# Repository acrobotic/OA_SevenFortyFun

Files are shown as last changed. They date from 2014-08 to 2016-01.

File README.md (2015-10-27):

## Ai\_Synth\_AVR

PCB design files (EAGLE) for a transistor-scale version of the μA741 Op-Amp
Integrated Circuit.

## Description

For more details, check out the product page at:

   * https://acrobotic.com/acr-00003

Designed by ACROBOTIC Industries in collaboration with Shane Petcavich.  
Please consider buying products from us to help fund future Open-Source 
projects like this! We’ll always put our best effort in every project, and 
release all our design files and code for you to use. 

## License

Released under the Creative Commons Attribution, Share-Alike license. Please 
check LICENSE.txt for more information. All text above must be included in any 
redistribution.

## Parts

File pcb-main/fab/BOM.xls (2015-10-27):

OA SevenFortyFun – BOM
Cisco Zabala (x1sc0@acrobotic.com) last updated: 27.10.2015
Manufacturer | Manuf. Part Number | Vendor | Vendor Part Number | Type | Designator | Qty | Description | Case | SMD, BGA, LCC, OR TH | Notes
 |  | Acrobotic | RES-00001-210 | Resistors | R1, R2 | 2 | RES 1K OHM 1/4W 5% AXIAL | AXIAL | TH
 |  | Acrobotic | RES-00001-347 |  | R3, R8 | 2 | RES 47K OHM 1/4W 5% AXIAL | AXIAL | TH | 50K OHM
 |  | Acrobotic | RES-00001-251 |  | R4 | 1 | RES 5.1K OHM 1/4W 5% AXIAL | AXIAL | TH | 5K OHM
 |  | Acrobotic | RES-00001-339 |  | R5 | 1 | RES 39K OHM 1/4W 5% AXIAL | AXIAL | TH
 |  | Acrobotic | RES-00001-247 |  | R6 | 1 | RES 4.7K OHM 1/4W 5% AXIAL | AXIAL | TH | 4.5K OHM
 |  | Acrobotic | RES-00001-275 |  | R7 | 1 | RES 7.5K OHM 1/4W 5% AXIAL | AXIAL | TH
 |  | Acrobotic | RES-00001-051 |  | R9, R11 | 2 | RES 51 OHM 1/4W 5% AXIAL | AXIAL | TH | 50 OHM
 |  | Acrobotic | RES-00001-024 |  | R10 | 1 | RES 24 OHM 1/4W 5% AXIAL | AXIAL | TH | 25 OHM
 |  | Acrobotic | CAP-00001-033 | Capacitors | C1 | 1 | CAP CER 33PF 200V 10% RADIAL | RADIAL | TH
 |  | Acrobotic | CHP-00040 | Transistors | Q1,Q2, Q5, Q6, Q7, Q8, Q9, Q10, Q11, Q12, Q13, Q14, Q16 | 13 | IC TRANS NPN SS GP 200MA TO-92 | TO-92 | TH
 |  | Acrobotic | CHP-00039 |  | Q3, Q4, Q15, Q17, Q18, Q19, Q20 | 7 | TRANSISTOR PNP 40V 200MA TO-92 | TO-92 | TH
 |  | Acrobotic | HWR-00002 | Hardware | - | 4 | 4-40 Screws |  | -
 |  | Acrobotic | HWR-00011 |  | - | 4 | 4-40 Standoffs |  | -
 |  | Acrobotic | ACR-00003 | PCB | - | 1 | Breadboard Adapter PCB |  | -
 |  | Acrobotic | ACR-00003 |  | - | 1 | SevenFortyFun PCB w Press-Fit Inserts |  | -
 |  | Acrobotic | CON-00036 | Connectors | [J1], J9 | 2 | CONN HEADER 8 POS 2.54 | 2x4 | TH
 |  | Acrobotic | HWR-00029 |  | J1, J2, J3, J4, J5, J6, J7, J8 | 8 | Press-fit Threaded Inserts | - | TH
 |  | Acrobotic | HWR-00028 |  | (J1), (J2), (J3), (J4), (J5), (J6), (J7), (J8) | 8 | 4-40 Thumb Screws | - | TH
 |  | Acrobotic | CON-00009 |  | (J9) | 1 | 0.1” Pitch, 20-Pin (Male) | - | TH
 |  | Acrobotic | ACR-00003 |  | Breakout cable | 1 | 2x4 IDC Cable | - | -

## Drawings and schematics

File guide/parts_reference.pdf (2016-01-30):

## ACROBOTIC SevenFortyFun Kit - Parts List

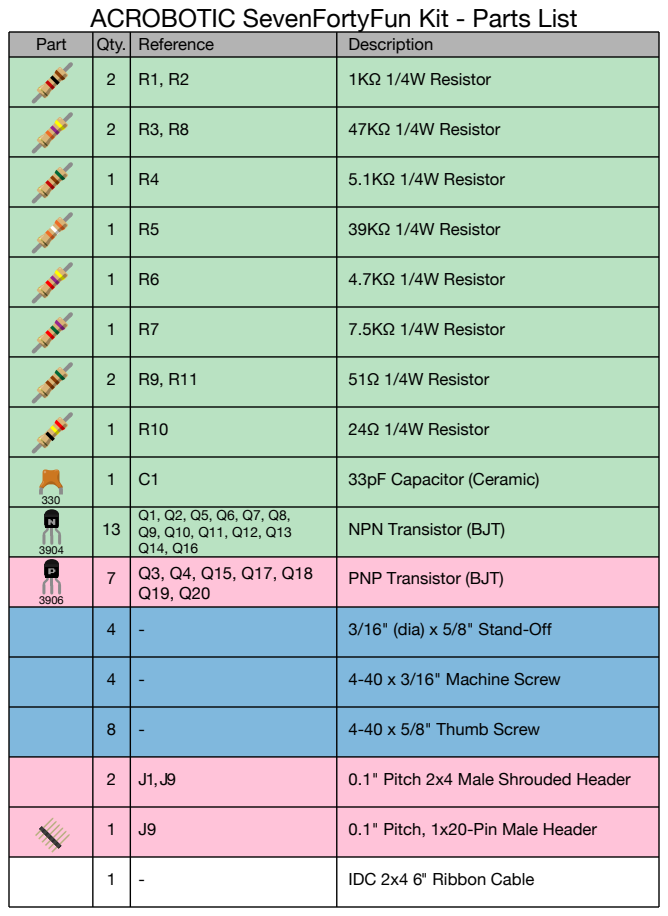
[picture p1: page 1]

Part | Qty. | Reference | Description
2 | R1, R2 | 1KΩ 1/4W Resistor

2 | R3, R8 | 47KΩ 1/4W Resistor

1 | R4 | 5.1KΩ 1/4W Resistor

1 | R5 | 39KΩ 1/4W Resistor

1 | R6 | 4.7KΩ 1/4W Resistor

1 | R7 | 7.5KΩ 1/4W Resistor

2 | R9, R11 | 51Ω 1/4W Resistor

1 | R10 | 24Ω 1/4W Resistor

330 | 1 | C1 | 33pF Capacitor (Ceramic)
3904 | | 13 | Q1, Q2, Q5, Q6, Q7, Q8, Q9, Q10, Q11, Q12, Q13 Q14, Q16 | NPN Transistor (BJT)

7 | Q3, Q4, Q15, Q17, Q18 Q19, Q20 | PNP Transistor (BJT)

4 | - | 3/16" (dia) x 5/8" Stand-Off

4 | - | 4-40 x 3/16" Machine Screw

8 | - | 4-40 x 5/8" Thumb Screw

2 | J1, J9 | 0.1" Pitch 2x4 Male Shrouded Header

1 | J9 | 0.1" Pitch, 1x20-Pin Male Header

1 | - | IDC 2x4 6" Ribbon Cable

For instructions, firmware, files please visit: http://github.com/acrobotic/OA_SevenFortyFun

BAG #1
BAG #2
BAG #3

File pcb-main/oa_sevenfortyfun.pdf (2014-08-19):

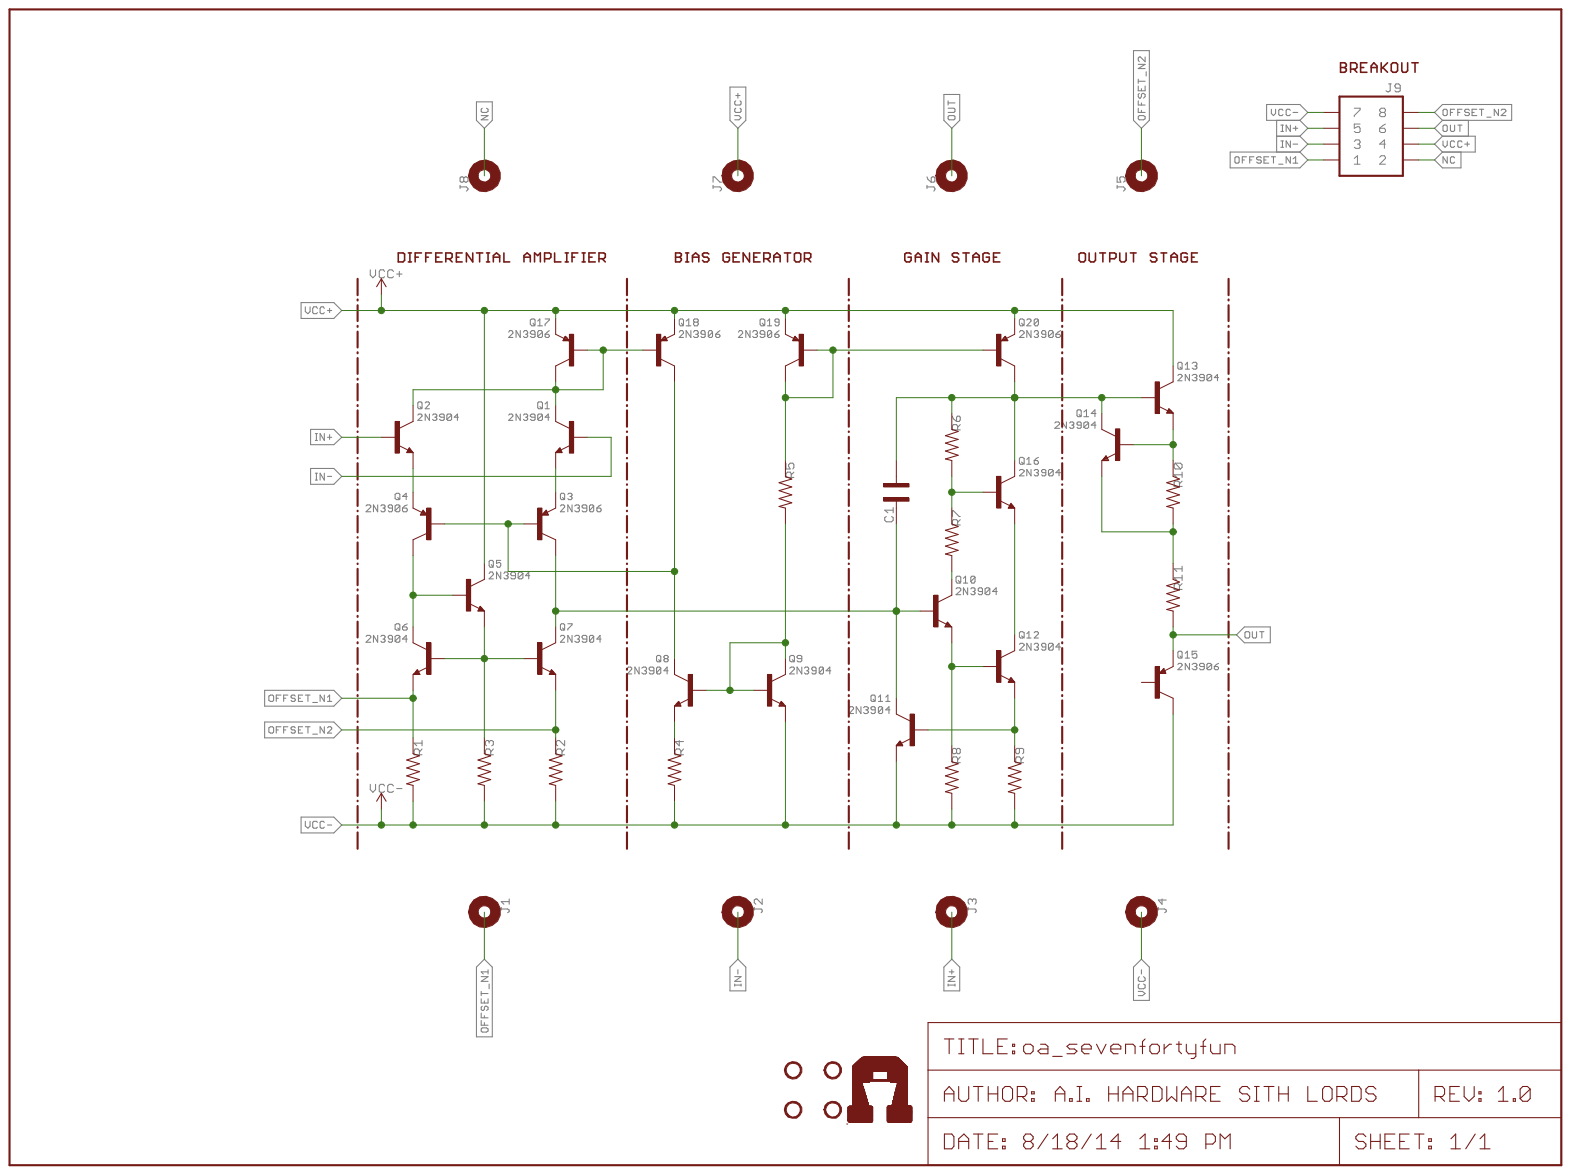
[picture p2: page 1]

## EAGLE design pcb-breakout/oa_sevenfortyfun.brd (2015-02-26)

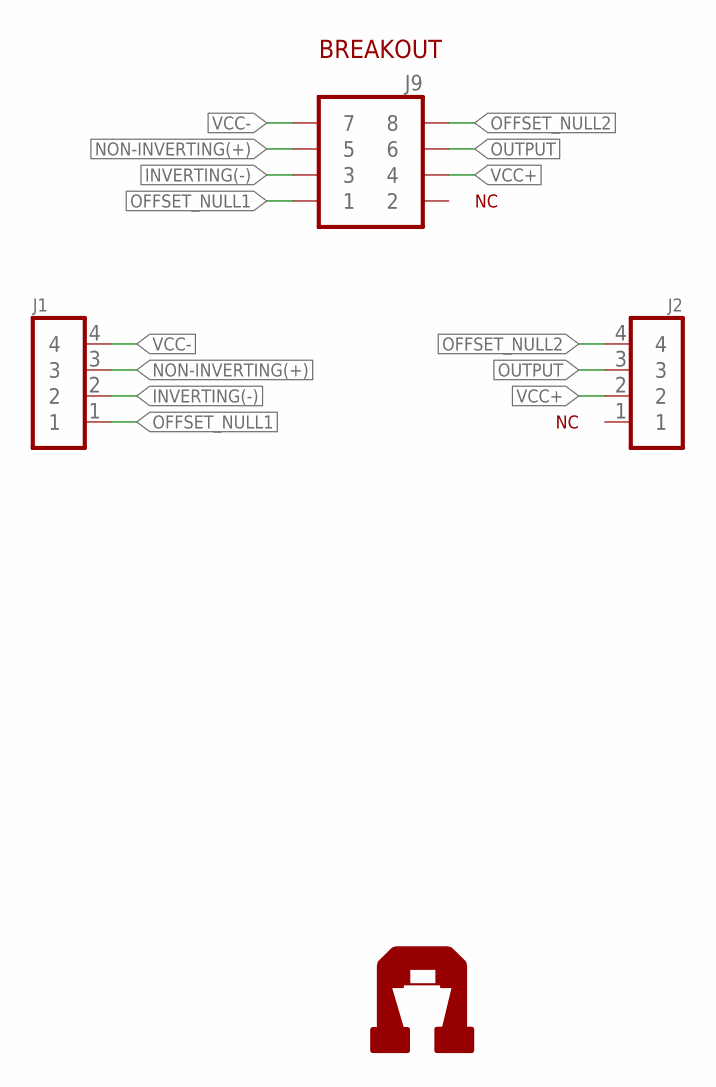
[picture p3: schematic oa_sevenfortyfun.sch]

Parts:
J1: 1X04NOSILK; 1X04-NOSILK
J2: 1X04NOFIRST; 1X04-NOFIRST
J9: 2X04SHR; 2X04-SHR
U$3: AI-LOGOXS; AI-LOGO-XS

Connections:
INVERTING(-): J1.2, J9.3
NON-INVERTING(+): J1.3, J9.5
OFFSET_NULL1: J1.1, J9.1
OFFSET_NULL2: J2.4, J9.8
OUTPUT: J2.3, J9.6
VCC+: J2.2, J9.4
VCC-: J1.4, J9.7

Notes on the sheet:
BREAKOUT

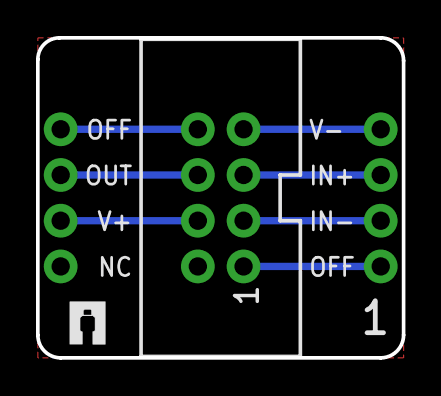
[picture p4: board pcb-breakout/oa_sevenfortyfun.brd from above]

Board: 2 copper layers, 20.3 x 17.8 mm, 4 parts (0 on the bottom side), 7 nets.

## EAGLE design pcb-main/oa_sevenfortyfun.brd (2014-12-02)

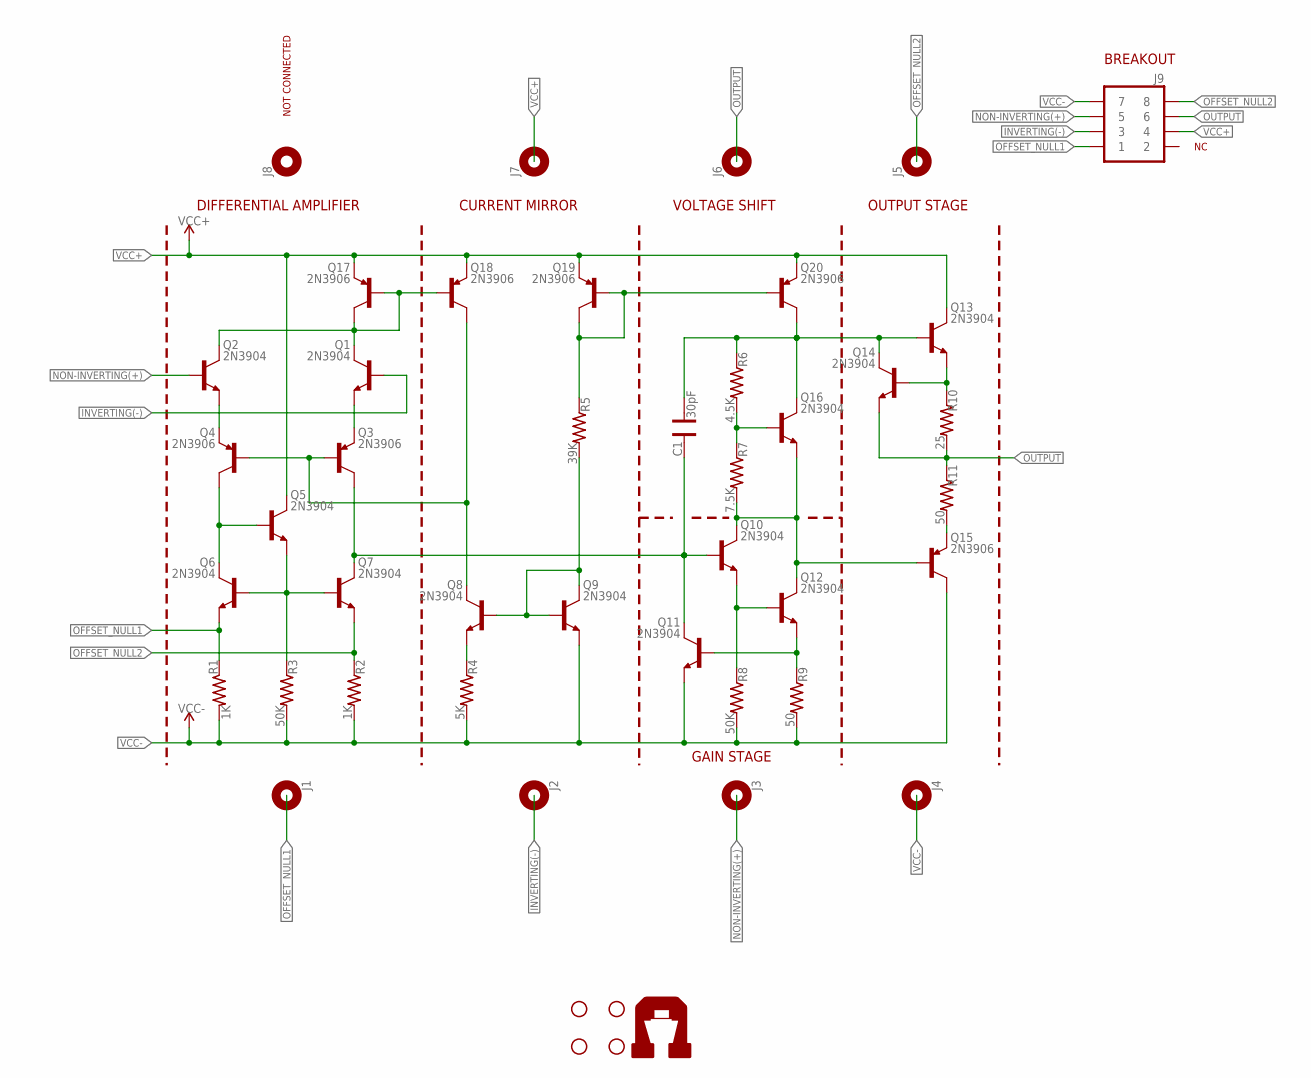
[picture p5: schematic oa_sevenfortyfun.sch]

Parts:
C1: 30pF; CAP-025X050
J1, J2, J3, J4, J5, J6, J7, J8: 1X01-TERM
J9: 2X04SHR; 2X04-SHR
Q1, Q2, Q5, Q6, Q7, Q8, Q9, Q10, Q11, Q12, Q13, Q14, Q16: 2N3904; TO-92-NPN
Q3, Q4, Q15, Q17, Q18, Q19, Q20: 2N3906; TO-92-PNP
R1, R2: 1K; RES-AXIAL-0.4
R3, R8: 50K; RES-AXIAL-0.4
R4: 5K; RES-AXIAL-0.4
R5: 39K; RES-AXIAL-0.4
R6: 4.5K; RES-AXIAL-0.4
R7: 7.5K; RES-AXIAL-0.4
R9, R11: 50; RES-AXIAL-0.4
R10: 25; RES-AXIAL-0.4
STANDOFF1, STANDOFF2, STANDOFF3, STANDOFF4: STAND-OFF4; STAND-OFF-4
U$3: AI-LOGOL; AI-LOGO-L

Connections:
INVERTING(-): J2.1, J9.3, Q1.2 (B)
unnamed: Q1.3 (C), Q2.3 (C), Q17.1 (C), Q17.2 (B), Q18.2 (B)
unnamed: Q2.1 (E), Q4.3 (E)
unnamed: Q1.1 (E), Q3.3 (E)
unnamed: Q4.1 (C), Q5.2 (B), Q6.3 (C)
unnamed: C1.2, Q3.1 (C), Q7.3 (C), Q10.2 (B), Q11.3 (C)
unnamed: Q5.1 (E), Q6.2 (B), Q7.2 (B), R3.P$1 (1)
unnamed: Q15.3 (E), R11.P$2 (2)
unnamed: Q3.2 (B), Q4.2 (B), Q8.3 (C), Q18.1 (C)
unnamed: Q8.1 (E), R4.P$1 (1)
unnamed: Q10.1 (E), Q12.2 (B), R8.P$1 (1)
unnamed: Q19.1 (C), Q19.2 (B), Q20.2 (B), R5.P$1 (1)
unnamed: Q8.2 (B), Q9.2 (B), Q9.3 (C), R5.P$2 (2)
unnamed: Q10.3 (C), Q12.3 (C), Q15.2 (B), Q16.1 (E), R7.P$2 (2)
unnamed: Q16.2 (B), R6.P$2 (2), R7.P$1 (1)
unnamed: Q11.2 (B), Q12.1 (E), R9.P$1 (1)
unnamed: C1.1, Q13.2 (B), Q14.3 (C), Q16.3 (C), Q20.1 (C), R6.P$1 (1)
unnamed: Q13.1 (E), Q14.2 (B), R10.P$1 (1)
NON-INVERTING(+): J3.1, J9.5, Q2.2 (B)
OFFSET_NULL1: J1.1, J9.1, Q6.1 (E), R1.P$1 (1)
OFFSET_NULL2: J5.1, J9.8, Q7.1 (E), R2.P$1 (1)
OUTPUT: J6.1, J9.6, Q14.1 (E), R10.P$2 (2), R11.P$1 (1)
VCC+: J7.1, J9.4, Q5.3 (C), Q13.3 (C), Q17.3 (E), Q18.3 (E), Q19.3 (E), Q20.3 (E)
VCC-: J4.1, J9.7, Q9.1 (E), Q11.1 (E), Q15.1 (C), R1.P$2 (2), R2.P$2 (2), R3.P$2 (2), R4.P$2 (2), R8.P$2 (2), R9.P$2 (2)

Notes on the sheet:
DIFFERENTIAL AMPLIFIER
CURRENT MIRROR
VOLTAGE SHIFT
OUTPUT STAGE
BREAKOUT
NOT CONNECTED
GAIN STAGE

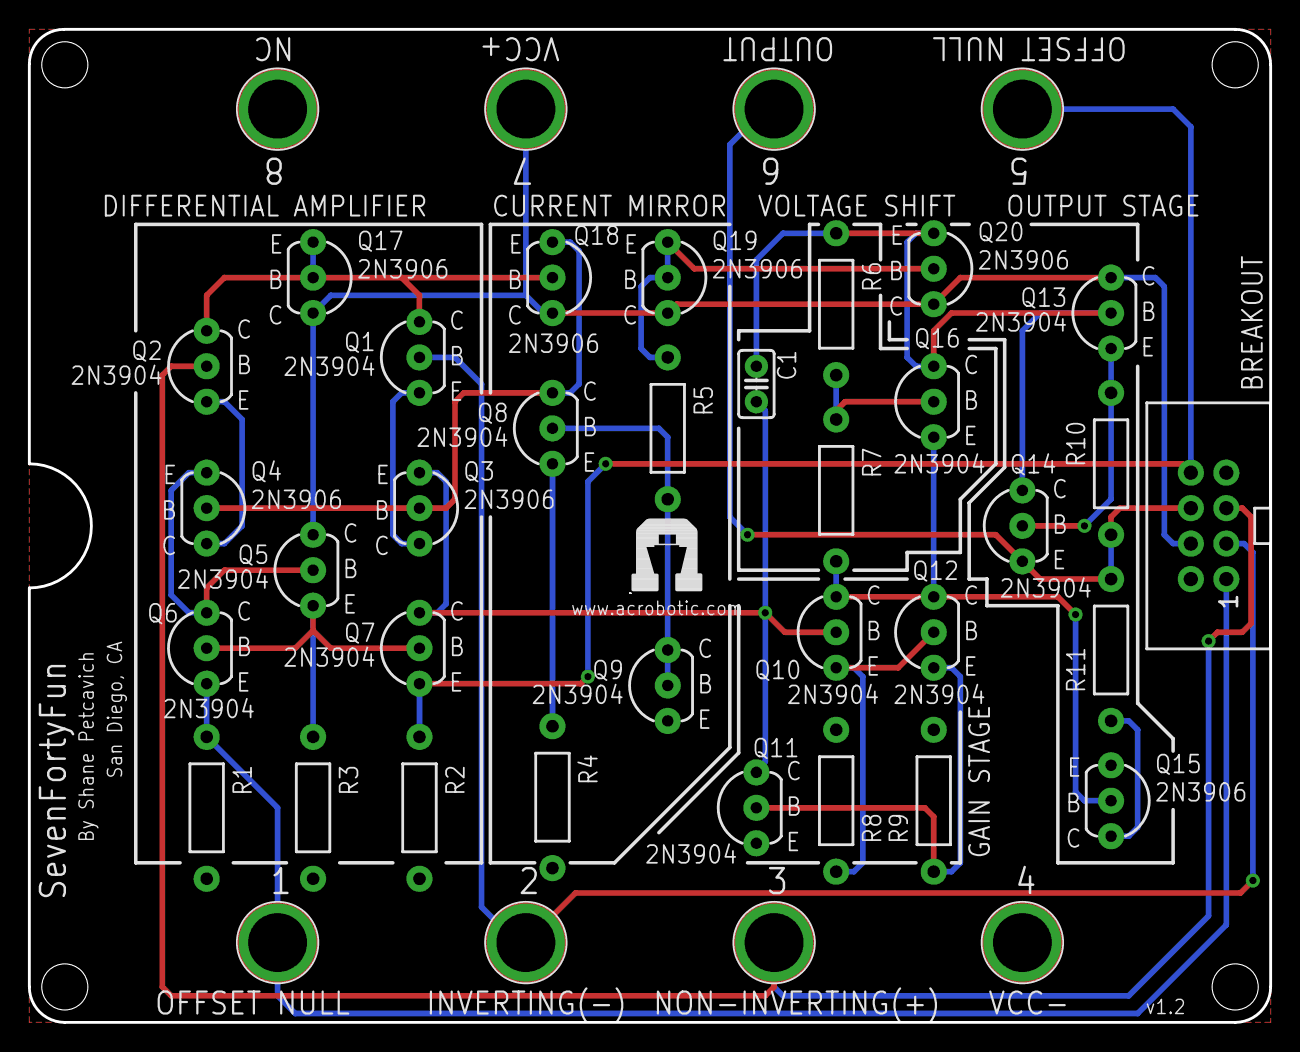
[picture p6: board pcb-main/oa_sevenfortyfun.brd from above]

Board: 2 copper layers, 88.9 x 71.1 mm, 46 parts (0 on the bottom side), 24 nets.

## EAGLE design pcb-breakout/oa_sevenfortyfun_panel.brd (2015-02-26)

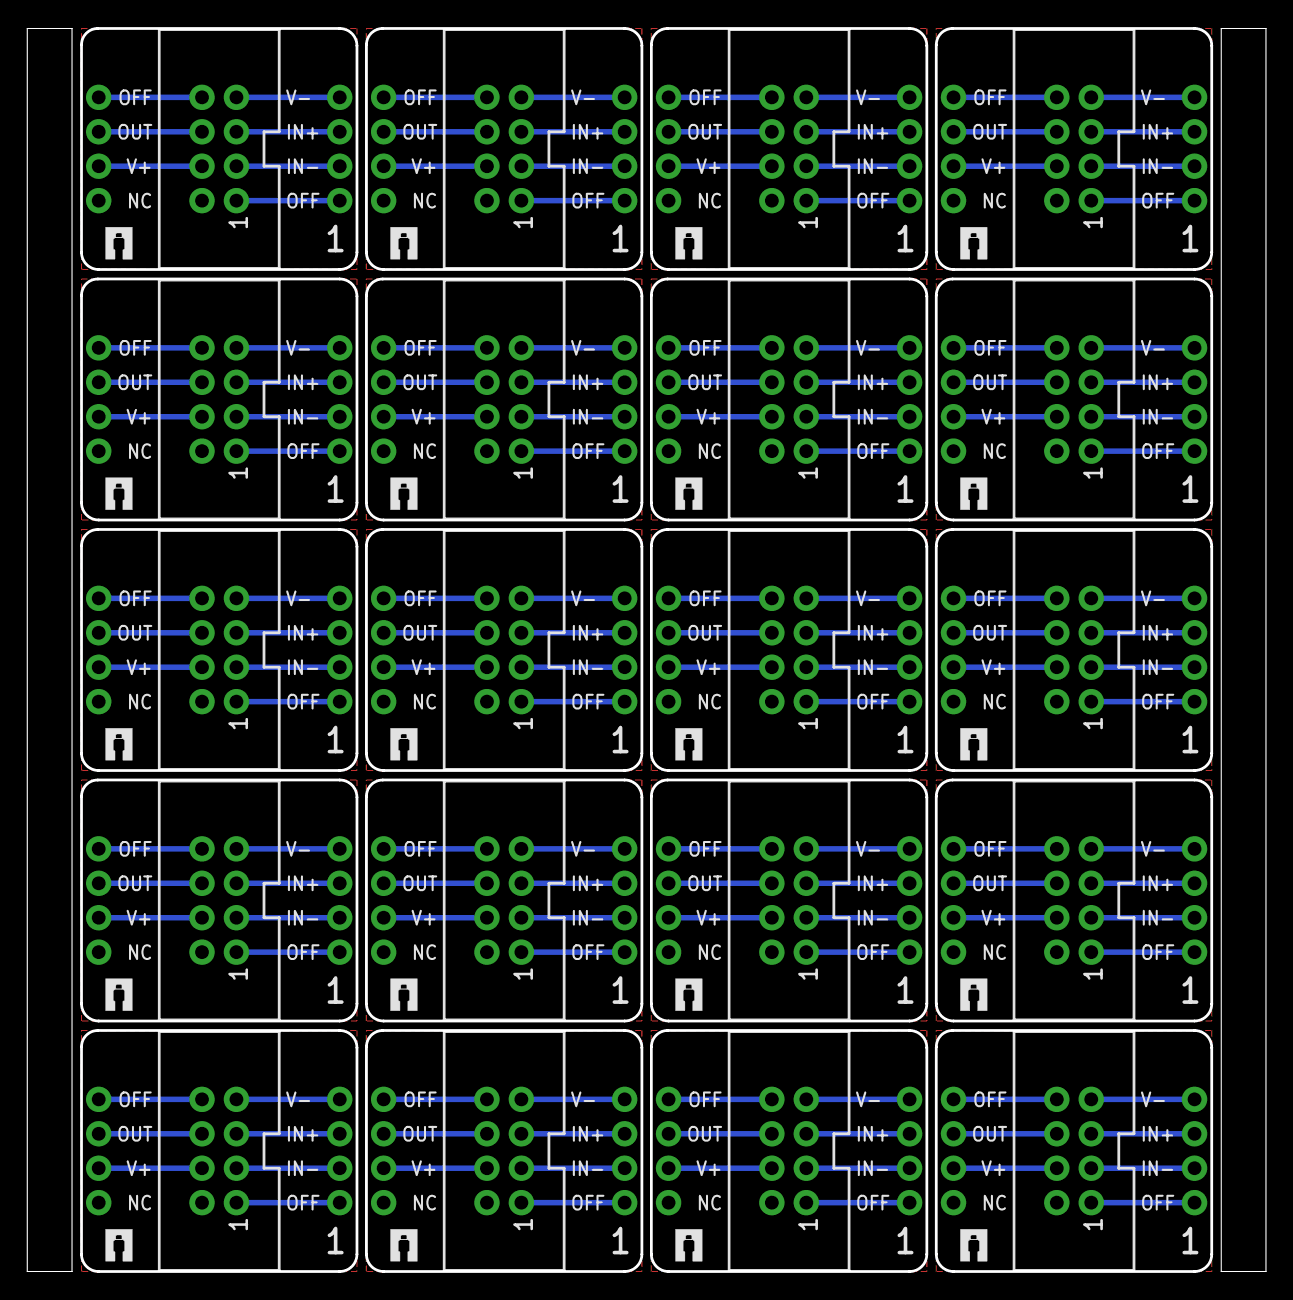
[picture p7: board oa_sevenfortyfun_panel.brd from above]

Board: 2 copper layers, 91.4 x 91.7 mm, 80 parts (0 on the bottom side), 140 nets.

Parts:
J1, J4, J7, J11, J14, J17, J20, J23, J26, J29, J32, J35, J38, J41, J44, J47, J50, J53, J56, J59: 1X04NOSILK; 1X04-NOSILK
J2, J5, J8, J12, J15, J18, J21, J24, J27, J30, J33, J36, J39, J42, J45, J48, J51, J54, J57, J60: 1X04NOFIRST; 1X04-NOFIRST
J3, J6, J9, J10, J13, J16, J19, J22, J25, J28, J31, J34, J37, J40, J43, J46, J49, J52, J55, J58: 2X04SHR; 2X04-SHR
U$1, U$2, U$3, U$4, U$5, U$6, U$7, U$8, U$9, U$10, U$11, U$12, U$13, U$14, U$15, U$16, U$17, U$18, U$19, U$20: AI-LOGOXS; AI-LOGO-XS

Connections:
INVERTING(-): J1.2, J9.3
INVERTING(-)1: J3.3, J4.2
INVERTING(-)2: J6.3, J7.2
INVERTING(-)3: J10.3, J11.2
INVERTING(-)4: J13.3, J14.2
INVERTING(-)5: J16.3, J17.2
INVERTING(-)6: J19.3, J20.2
INVERTING(-)7: J22.3, J23.2
INVERTING(-)8: J25.3, J26.2
INVERTING(-)9: J28.3, J29.2
INVERTING(-)10: J31.3, J32.2
INVERTING(-)11: J34.3, J35.2
INVERTING(-)12: J37.3, J38.2
INVERTING(-)13: J40.3, J41.2
INVERTING(-)14: J43.3, J44.2
INVERTING(-)15: J46.3, J47.2
INVERTING(-)16: J49.3, J50.2
INVERTING(-)17: J52.3, J53.2
INVERTING(-)18: J55.3, J56.2
INVERTING(-)19: J58.3, J59.2
NON-INVERTING(+): J1.3, J9.5
NON-INVERTING(+)1: J3.5, J4.3
NON-INVERTING(+)2: J6.5, J7.3
NON-INVERTING(+)3: J10.5, J11.3
NON-INVERTING(+)4: J13.5, J14.3
NON-INVERTING(+)5: J16.5, J17.3
NON-INVERTING(+)6: J19.5, J20.3
NON-INVERTING(+)7: J22.5, J23.3
NON-INVERTING(+)8: J25.5, J26.3
NON-INVERTING(+)9: J28.5, J29.3
NON-INVERTING(+)10: J31.5, J32.3
NON-INVERTING(+)11: J34.5, J35.3
NON-INVERTING(+)12: J37.5, J38.3
NON-INVERTING(+)13: J40.5, J41.3
NON-INVERTING(+)14: J43.5, J44.3
NON-INVERTING(+)15: J46.5, J47.3
NON-INVERTING(+)16: J49.5, J50.3
NON-INVERTING(+)17: J52.5, J53.3
NON-INVERTING(+)18: J55.5, J56.3
NON-INVERTING(+)19: J58.5, J59.3
OFFSET_NULL1: J1.1, J9.1
OFFSET_NULL2: J2.4, J9.8
OFFSET_NULL3: J3.8, J5.4
OFFSET_NULL4: J3.1, J4.1
OFFSET_NULL5: J6.8, J8.4
OFFSET_NULL6: J6.1, J7.1
OFFSET_NULL7: J10.8, J12.4
OFFSET_NULL8: J10.1, J11.1
OFFSET_NULL9: J13.8, J15.4
OFFSET_NULL10: J13.1, J14.1
OFFSET_NULL11: J16.8, J18.4
OFFSET_NULL12: J16.1, J17.1
OFFSET_NULL13: J19.8, J21.4
OFFSET_NULL14: J19.1, J20.1
OFFSET_NULL15: J22.8, J24.4
OFFSET_NULL16: J22.1, J23.1
OFFSET_NULL17: J25.8, J27.4
OFFSET_NULL18: J25.1, J26.1
OFFSET_NULL19: J28.8, J30.4
OFFSET_NULL20: J28.1, J29.1
OFFSET_NULL21: J31.8, J33.4
OFFSET_NULL22: J31.1, J32.1
OFFSET_NULL23: J34.8, J36.4
OFFSET_NULL24: J34.1, J35.1
OFFSET_NULL25: J37.8, J39.4
OFFSET_NULL26: J37.1, J38.1
OFFSET_NULL27: J40.8, J42.4
OFFSET_NULL28: J40.1, J41.1
OFFSET_NULL29: J43.8, J45.4
OFFSET_NULL30: J43.1, J44.1
OFFSET_NULL31: J46.8, J48.4
OFFSET_NULL32: J46.1, J47.1
OFFSET_NULL33: J49.8, J51.4
OFFSET_NULL34: J49.1, J50.1
OFFSET_NULL35: J52.8, J54.4
OFFSET_NULL36: J52.1, J53.1
OFFSET_NULL37: J55.8, J57.4
OFFSET_NULL38: J55.1, J56.1
OFFSET_NULL39: J58.8, J60.4
OFFSET_NULL40: J58.1, J59.1
OUTPUT: J2.3, J9.6
OUTPUT1: J3.6, J5.3
OUTPUT2: J6.6, J8.3
OUTPUT3: J10.6, J12.3
OUTPUT4: J13.6, J15.3
OUTPUT5: J16.6, J18.3
OUTPUT6: J19.6, J21.3
OUTPUT7: J22.6, J24.3
OUTPUT8: J25.6, J27.3
OUTPUT9: J28.6, J30.3
OUTPUT10: J31.6, J33.3
OUTPUT11: J34.6, J36.3
OUTPUT12: J37.6, J39.3
OUTPUT13: J40.6, J42.3
OUTPUT14: J43.6, J45.3
OUTPUT15: J46.6, J48.3
OUTPUT16: J49.6, J51.3
OUTPUT17: J52.6, J54.3
OUTPUT18: J55.6, J57.3
OUTPUT19: J58.6, J60.3
VCC+: J2.2, J9.4
VCC+1: J3.4, J5.2
VCC+2: J6.4, J8.2
VCC+3: J10.4, J12.2
VCC+4: J13.4, J15.2
VCC+5: J16.4, J18.2
VCC+6: J19.4, J21.2
VCC+7: J22.4, J24.2
VCC+8: J25.4, J27.2
VCC+9: J28.4, J30.2
VCC+10: J31.4, J33.2
VCC+11: J34.4, J36.2
VCC+12: J37.4, J39.2
VCC+13: J40.4, J42.2
VCC+14: J43.4, J45.2
VCC+15: J46.4, J48.2
VCC+16: J49.4, J51.2
VCC+17: J52.4, J54.2
VCC+18: J55.4, J57.2
VCC+19: J58.4, J60.2
VCC-: J1.4, J9.7
VCC-1: J3.7, J4.4
VCC-2: J6.7, J7.4
VCC-3: J10.7, J11.4
VCC-4: J13.7, J14.4
VCC-5: J16.7, J17.4
VCC-6: J19.7, J20.4
VCC-7: J22.7, J23.4
VCC-8: J25.7, J26.4
VCC-9: J28.7, J29.4
VCC-10: J31.7, J32.4
VCC-11: J34.7, J35.4
VCC-12: J37.7, J38.4
VCC-13: J40.7, J41.4
VCC-14: J43.7, J44.4
VCC-15: J46.7, J47.4
VCC-16: J49.7, J50.4
VCC-17: J52.7, J53.4
VCC-18: J55.7, J56.4
VCC-19: J58.7, J59.4

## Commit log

2014-08-18 Working on silkscreen
    [oa_sevenfortyfun.brd, oa_sevenfortyfun.sch]
2014-08-19 starting to route
    [oa_sevenfortyfun.brd, oa_sevenfortyfun.sch]
2014-08-19 Routed. Worked on silkscreen.
    [oa_sevenfortyfun.brd, oa_sevenfortyfun.sch]
2014-08-19 added breakout board
    [oa_sevenfortyfun.brd, oa_sevenfortyfun.sch]
2014-08-20 adding gerbers
    [oa_sevenfortyfun.brd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]
2014-08-20 matching functional blocks to v1.0
    [oa_sevenfortyfun.brd, oa_sevenfortyfun.sch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]
2014-08-21 minor silkscreen change
    [oa_sevenfortyfun.brd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]
2014-08-22 updated to EAGLE 7
    [oa_sevenfortyfun.brd, oa_sevenfortyfun.sch]
2014-09-05 adding BOM
    [BOM.xls]
2014-09-14 added PCB to BOM
    [BOM.xls]
2014-11-27 regenerated gerbers
    [oa_sevenfortyfun.brd]
2014-12-02 updated files
    [oa_sevenfortyfun.brd, oa_sevenfortyfun.sch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]
2014-12-02 latest update (silkscreen changes)
    [oa_sevenfortyfun.brd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]
2014-12-02 updated version on schematic
    [oa_sevenfortyfun.sch]
2015-02-26 panelized breakout pcb
    [oa_sevenfortyfun.brd, oa_sevenfortyfun.sch, oa_sevenfortyfun_panel.brd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]
2015-10-27 updating guides
    [BOM.xls]
